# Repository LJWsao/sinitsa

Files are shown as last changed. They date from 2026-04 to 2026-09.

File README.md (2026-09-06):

KiCAD files for the all band receiver. This can pick up strong local sources of RF such as AM and FM radio stations. It is based on the 
Amazing All Band Receiver by Charles Wenzel: https://techlib.com/electronics/allband.htm

Screenshot 2026-09-06 at 6 56 52 PM

Screenshot 2026-09-06 at 6 58 10 PM

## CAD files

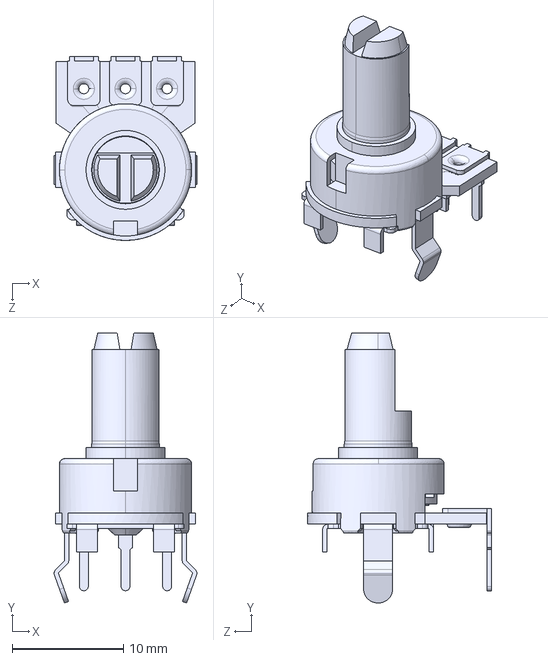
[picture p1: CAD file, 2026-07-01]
all_band_rec/3D_models/User Library-p120pk-f20.STEP
12.8 x 24.3 x 16.6 mm

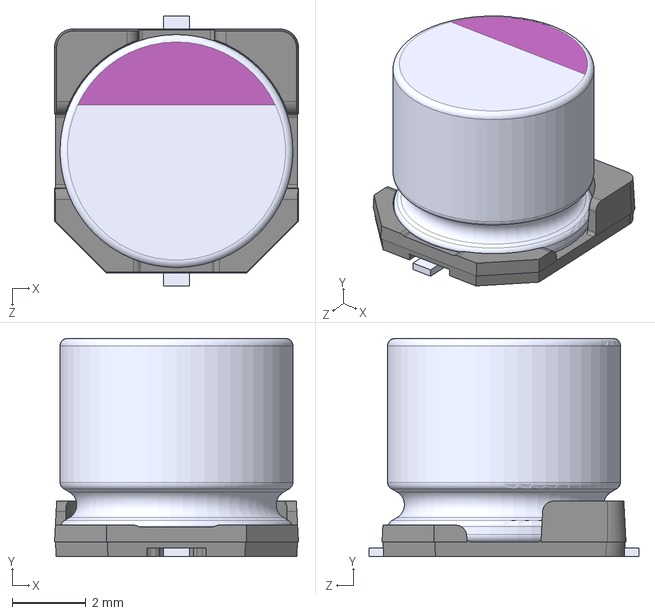
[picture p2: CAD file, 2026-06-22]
all_band_rec/3D_models/220ufElec_16SVPK220M.STEP
6.60 x 5.90 x 7.30 mm

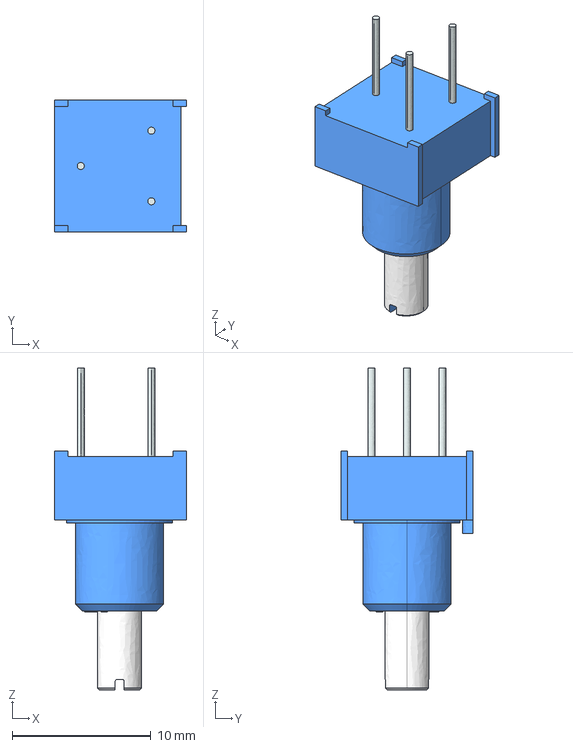
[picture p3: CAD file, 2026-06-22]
all_band_rec/3D_models/POT_3D_3310y-001.stp
9.52 x 9.52 x 23.2 mm

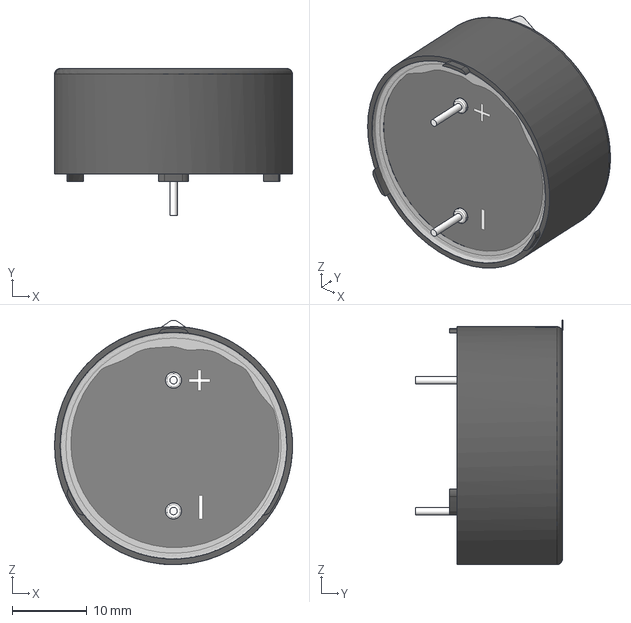
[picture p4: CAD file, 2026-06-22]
all_band_rec/3D_models/SPKR_AST-03208MR-R.step
31.9 x 19.7 x 32.7 mm

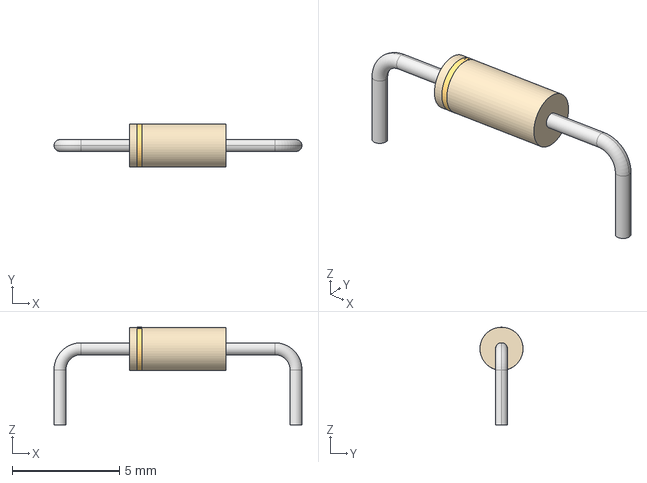
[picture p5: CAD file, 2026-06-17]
all_band_rec/3D_models/DO-35_STM.step
11.6 x 2.01 x 4.55 mm

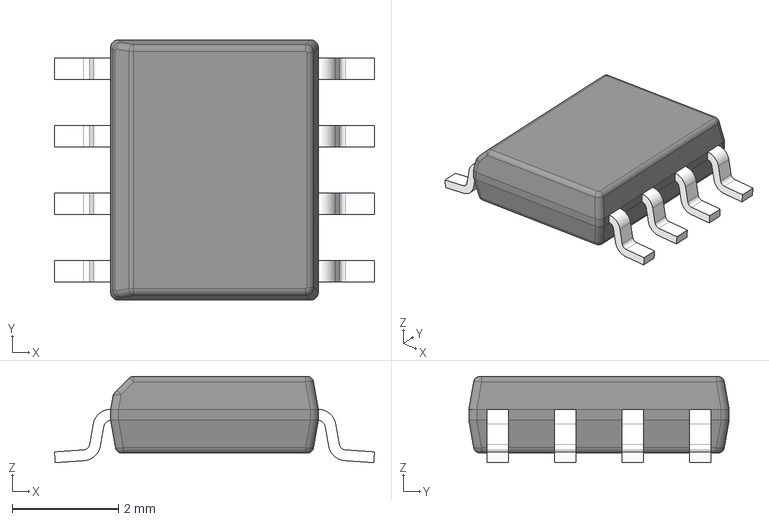
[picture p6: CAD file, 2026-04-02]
all_band_rec/3D_models/lm358DR_D0008A.stp
6.02 x 4.90 x 1.63 mm
BODY-SO
LEAD-D0008A x 8

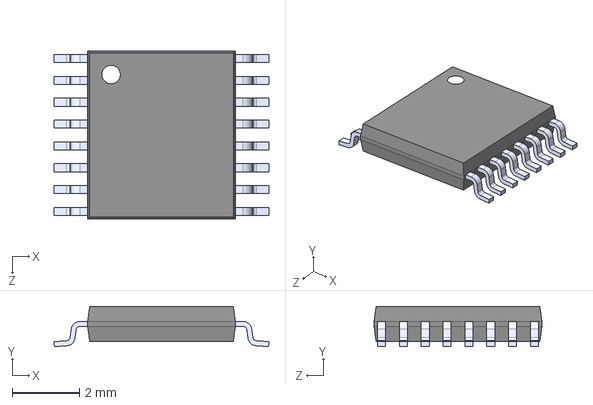
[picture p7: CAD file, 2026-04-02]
all_band_rec/3D_models/CD4053BPWR.step
6.40 x 1.20 x 5.00 mm

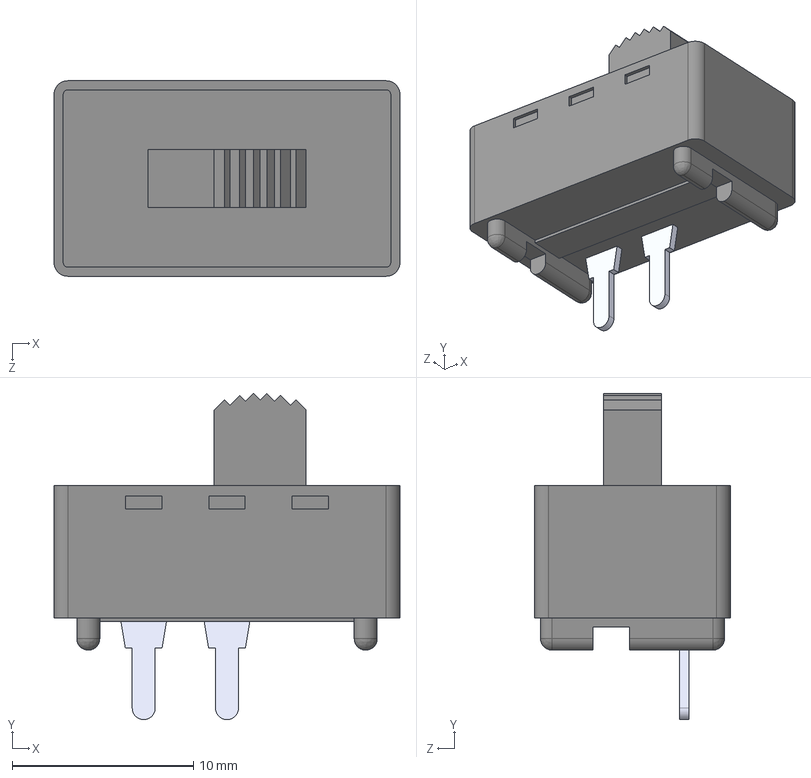
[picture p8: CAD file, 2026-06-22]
all_band_rec/3D_models/L101011MS02Q.STEP
19.1 x 18.0 x 10.8 mm

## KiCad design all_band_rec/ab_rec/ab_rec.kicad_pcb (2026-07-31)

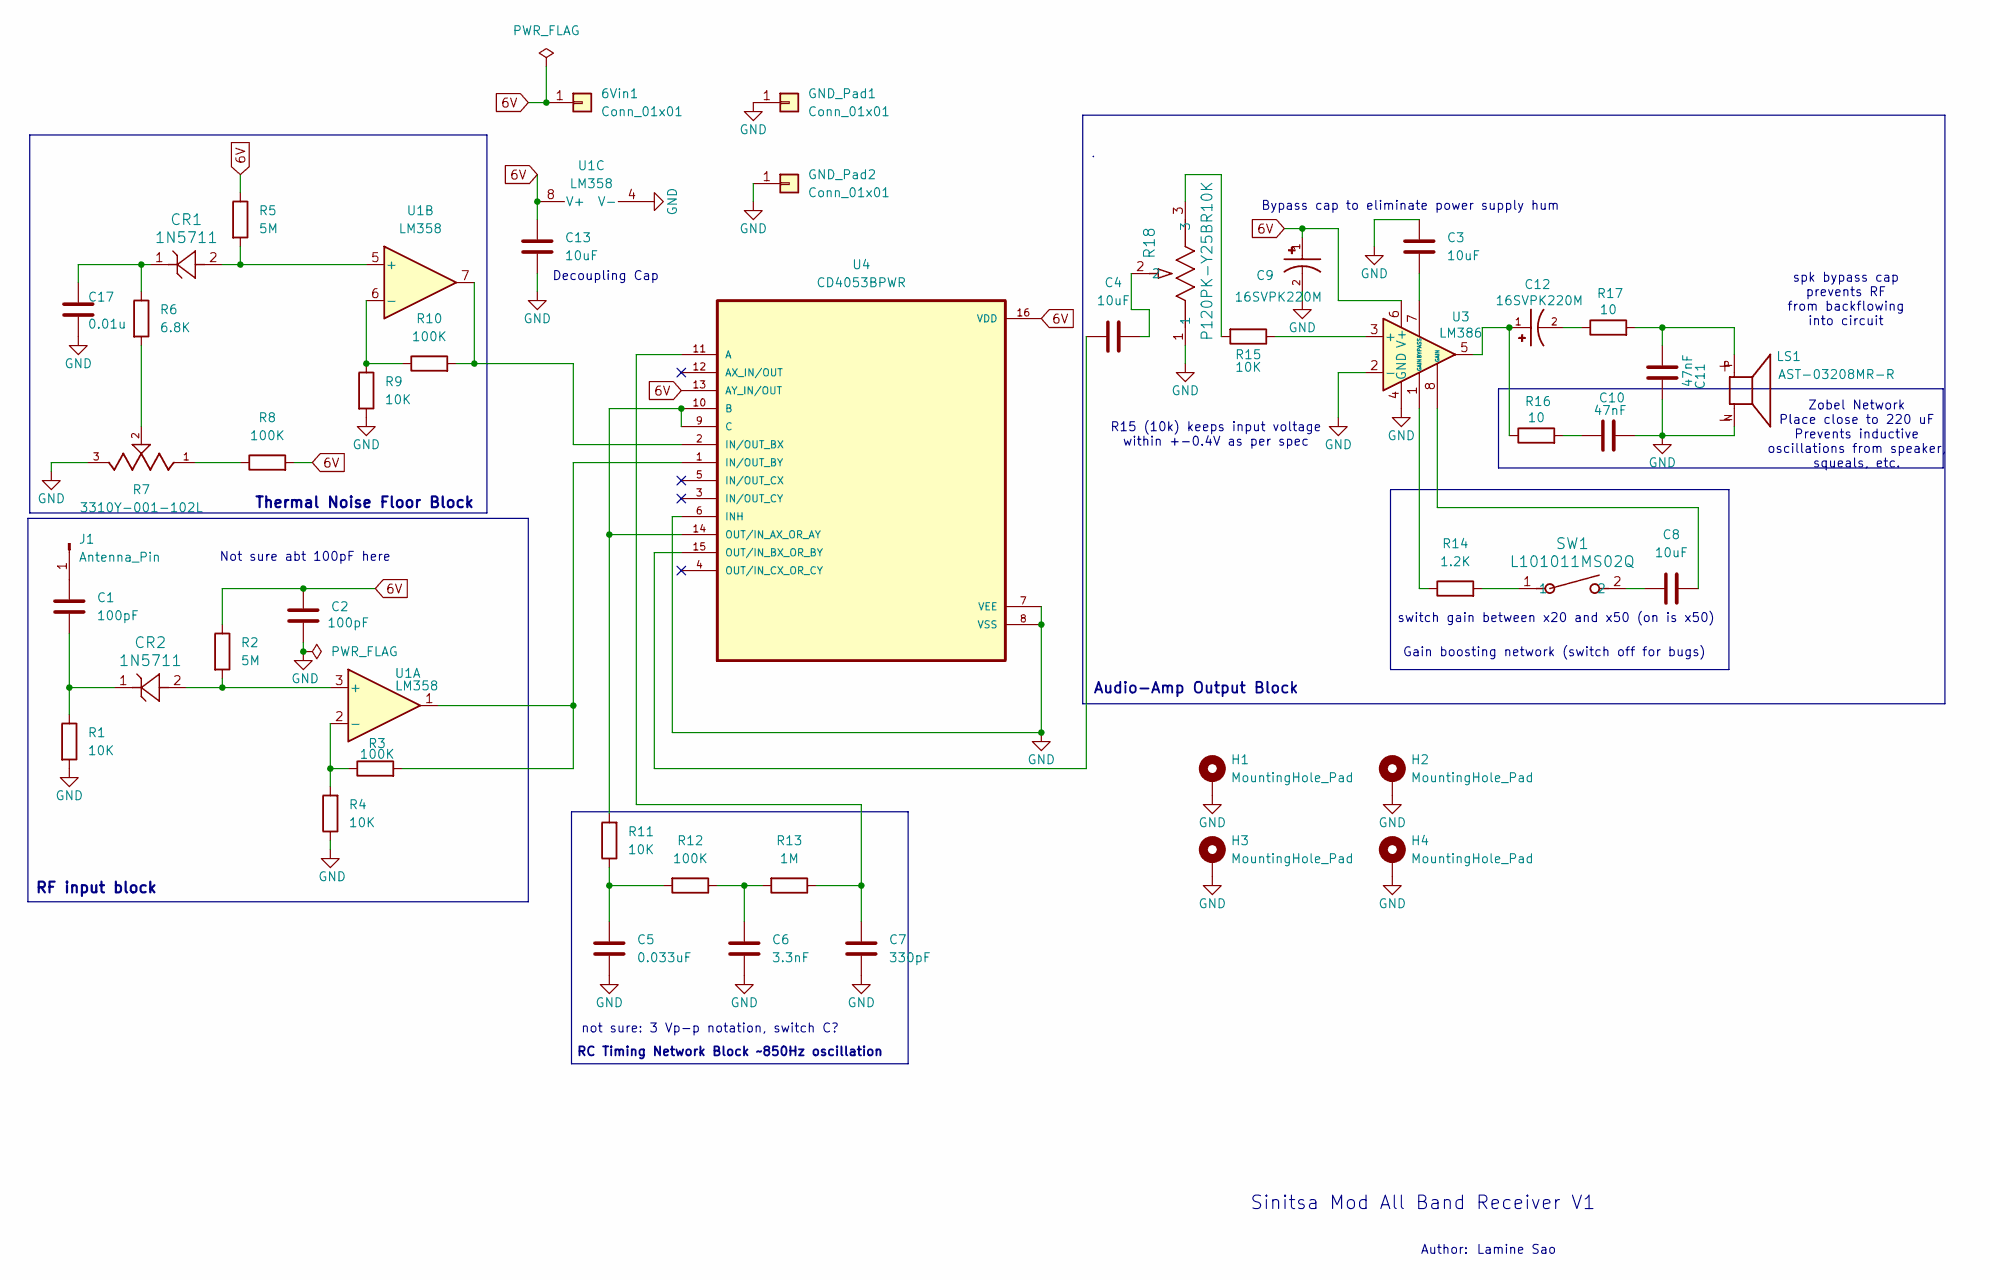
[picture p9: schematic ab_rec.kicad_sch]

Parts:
6Vin1: Conn_01x01; TestPoint_Pad_3.0x3.0mm
C1, C2: 100pF; C_0603_1608Metric_Pad1.08x0.95mm_HandSolder
C3, C4, C8, C13: 10uF; C_0805_2012Metric_Pad1.18x1.45mm_HandSolder
C5: 0.033uF; C_0805_2012Metric_Pad1.18x1.45mm_HandSolder
C6: 3.3nF; C_0603_1608Metric_Pad1.08x0.95mm_HandSolder
C7: 330pF; C_0603_1608Metric_Pad1.08x0.95mm_HandSolder
C9, C12: 16SVPK220M; CAP_16SVPK220M; PARTREV 28-Jun-19
C10, C11: 47nF; C_0603_1608Metric_Pad1.08x0.95mm_HandSolder
C17: 0.01u; C_0603_1608Metric
CR1, CR2: 1N5711; DO-35_STM_5711
GND_Pad1, GND_Pad2: Conn_01x01; TestPoint_Pad_3.0x3.0mm
H1, H2, H3, H4: MountingHole_Pad; MountingHole_3.5mm_Pad_Via
J1: Antenna_Pin; TestPoint_Pad_3.0x3.0mm
LS1: AST-03208MR-R; SPKR_AST-03208MR-R; PARTREV C
R1, R4, R9, R11, R15: 10K; R_0805_2012Metric_Pad1.20x1.40mm_HandSolder
R2, R5: 5M; R_0805_2012Metric_Pad1.20x1.40mm_HandSolder
R3, R10, R12: 100K; R_0805_2012Metric_Pad1.20x1.40mm_HandSolder
R6: 6.8K; R_0805_2012Metric_Pad1.20x1.40mm_HandSolder
R7: 3310Y-001-102L; POT_TRIM_3310Y-001-102L
R8: 100K; R_1206_3216Metric_Pad1.30x1.75mm_HandSolder
R13: 1M; R_1206_3216Metric_Pad1.30x1.75mm_HandSolder
R14: 1.2K; R_1206_3216Metric_Pad1.30x1.75mm_HandSolder
R16, R17: 10; R_1206_3216Metric_Pad1.30x1.75mm_HandSolder
R18: P120PK-Y25BR10K; POT_P120PK-x25_TTE
SW1: L101011MS02Q; SW_1MS02Q_CNK_Slide_Switch
U1: LM358; lm358-D8-L
U3: LM386
U4: CD4053BPWR; SOP65P640X120-16N

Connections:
6V: 6Vin1.1, C2.1, C9.1, C13.1, R2.1, R5.1, R8.2, U1.8 (V+), U3.6 (V+), U4.13 (AY_IN/OUT), U4.16 (VDD)
GND: C2.2, C3.2, C5.1, C6.1, C7.1, C9.2, C10.2, C11.2, C13.2, C17.2, GND_Pad1.1, GND_Pad2.1, H1.1, H2.1, H3.1, H4.1, LS1.N, R1.2, R4.1, R7.3, R9.2, R18.1, U1.4 (V-), U3.2 (-), U3.4 (GND), U4.6 (INH), U4.7 (VEE), U4.8 (VSS); also elsewhere on the board
unnamed: C1.2, CR2.1, R1.1
unnamed: C4.2, R18.2
unnamed: C5.2, R11.1, R12.2
unnamed: C6.2, R12.1, R13.2
unnamed: C8.1, SW1.2
unnamed: C8.2, U3.8 (GAIN)
unnamed: C10.1, R16.2
unnamed: C11.1, LS1.P, R17.2
unnamed: C12.1, R16.1, U3.5
unnamed: C12.2, R17.1
unnamed: C17.1, CR1.1, R6.1
unnamed: C1.1, J1.1
unnamed: R6.2, R7.2
unnamed: R7.1, R8.1
unnamed: R14.1, U3.1 (GAIN)
unnamed: R14.2, SW1.1
unnamed: R15.2, R18.3
unnamed: CR2.2, R2.2, U1.3 (+)
unnamed: R3.1, R4.2, U1.2 (-)
unnamed: CR1.2, R5.2, U1.5 (+)
unnamed: R9.1, R10.1, U1.6 (-)
unnamed: R15.1, U3.3 (+)
unnamed: C3.1, U3.7 (BYPASS)
unnamed: C7.2, R13.1, U4.11 (A)
unnamed: R11.2, U4.9 (C), U4.10 (B), U4.14 (OUT/IN_AX_OR_AY)
unnamed: R10.2, U1.7, U4.2 (IN/OUT_BX)
unnamed: R3.2, U1.1, U4.1 (IN/OUT_BY)
unnamed: C4.1, U4.15 (OUT/IN_BX_OR_BY)

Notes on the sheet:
Zobel Network Place close to 220 uF Prevents inductive oscillations from speaker, squeals, etc.
Decoupling Cap
Thermal Noise Floor Block
Lamine Sao
Bypass cap to eliminate power supply hum
not sure: 3 Vp-p notation, switch C?
R15 (10k) keeps input voltage within +-0.4V as per spec
switch gain between x20 and x50 (on is x50)
Author:
Gain boosting network (switch off for bugs)
RF input block
Audio-Amp Output Block
RC Timing Network Block ~850Hz oscillation
spk bypass cap prevents RF from backflowing into circuit
Not sure abt 100pF here
Sinitsa Mod All Band Receiver V1

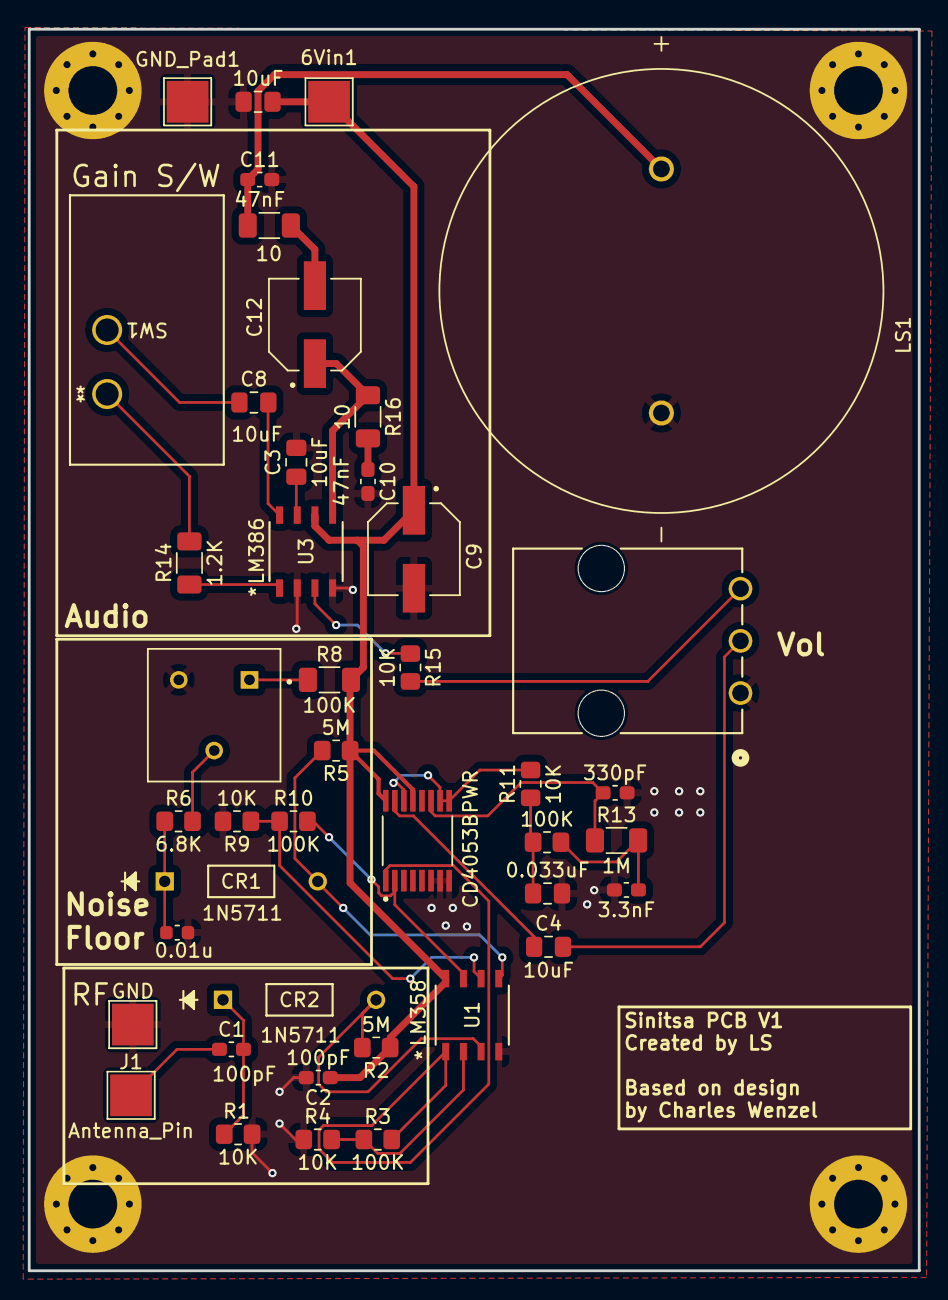
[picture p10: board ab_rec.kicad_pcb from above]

Board: 2 copper layers, 63.9 x 89.2 mm, 47 parts (0 on the bottom side), 30 nets.

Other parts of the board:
GND: Conn_01x01; TestPoint_Pad_3.0x3.0mm

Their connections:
GND: GND.1; also elsewhere on the board

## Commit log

2026-04-02 edits backups
    [CD4053BPWR.step, ab_rec.kicad_sch]
2026-04-02 schematic update
    [ab_rec.kicad_sch, lm358DR_D0008A.stp, lm386M-1.stp]
2026-05-03 Schematic updates
2026-05-03 Completed schematic, still finishing footprints
    [ab_rec.kicad_sch]
2026-05-03 fixed (maybe?) audio output section
    [ab_rec.kicad_sch]
2026-06-17 Minor schematic changes (fixed zobel, added more decoupling caps), still having ERC Power rules be sad
    [ab_rec.kicad_sch]
2026-06-17 Added footprints and symbols, 3D models for SPST slide switch and 1N5711 diodes
    [DO-35_STM.step, ab_rec.kicad_sch]
2026-06-18 Added all footprints, most 3D models, ERC rules check runs with no errors or warnings :)
    [ab_rec.kicad_sch]
2026-06-18 minor change and backup
    [ab_rec.kicad_sch]
2026-06-19 fixed switch to match numbering between footprint and symbol
    [ab_rec.kicad_sch]
2026-06-22 Added symbols, footprints, and models for lin pots and speaker
    [POT_3D_3310y-001.stp, SPKR_AST-03208MR-R.step, ab_rec.kicad_sch]
2026-06-22 All footprints and symbols updated properly, started pcb layout
    [220ufElec_16SVPK220M.STEP, L101011MS02Q.STEP, ab_rec.kicad_pcb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]
2026-06-22 pcb layout organization
    [ab_rec.kicad_pcb, ab_rec.kicad_sch]
2026-07-01 PCB V1 Layout Completed yay!!!
    [User Library-p120pk-f20.STEP, ab_rec.kicad_pcb, ab_rec.kicad_sch]
2026-07-01 minor silkscreen edits
    [ab_rec.kicad_pcb]
2026-07-01 Minor routing fix to get rid of sharp corners
    [ab_rec.kicad_pcb]
2026-07-01 Layout mounting hole fix and silkscreen edit
    [ab_rec.kicad_pcb]
2026-07-31 Added ground pad for antenna in RF section
    [ab_rec.kicad_pcb, ab_rec.kicad_sch]
